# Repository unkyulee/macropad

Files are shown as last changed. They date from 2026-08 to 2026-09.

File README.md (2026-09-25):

# Macro Pad 

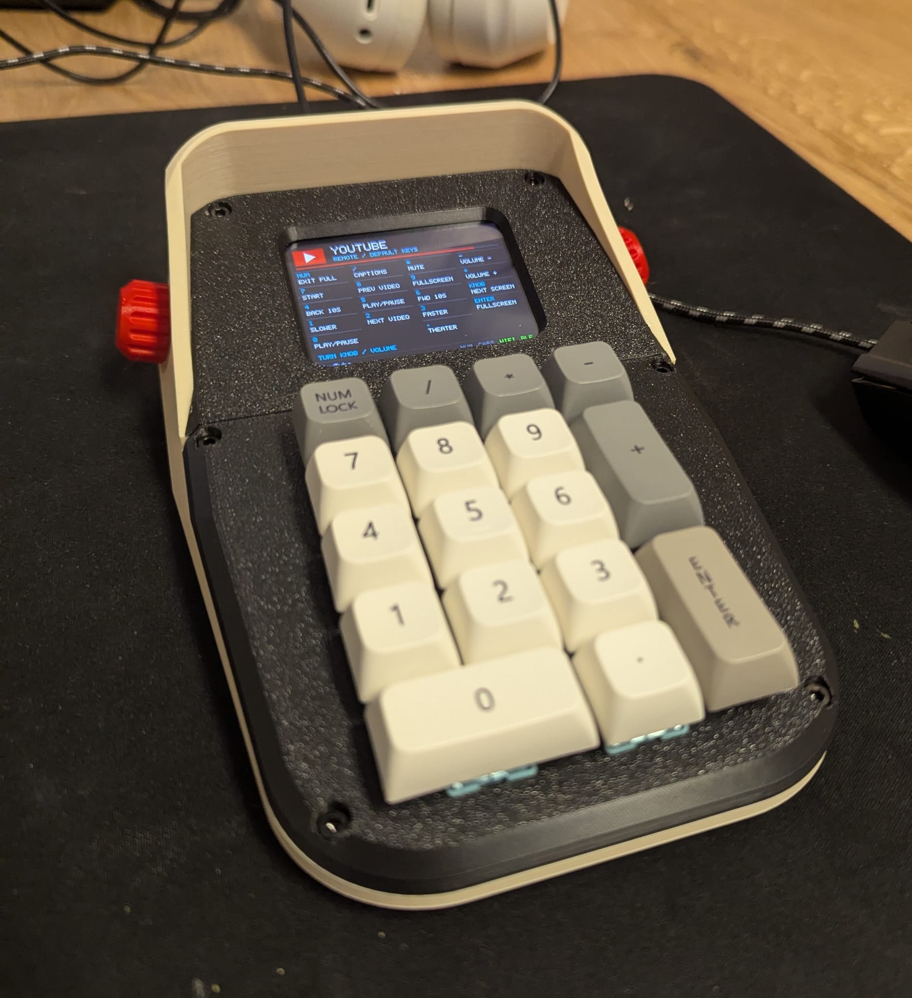
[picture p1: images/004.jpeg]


This is a number pad that also works as a macro pad. You can assign a different function to each key and save up to five different configurations.

I adjusted the overall dimensions and repositioned the knob to give it better proportions. I really like its size. It is quite chunky and has a strong presence on the desk. Since a number pad is usually idle most of the time, the screen displays a clock when it is not being used.

The screen can also play GIFs or turn the device into a standalone calculator. It connects to a PC or phone via Bluetooth Low Energy (BLE).

It solves several problems for me. I can type numbers much more comfortably, and most importantly, I can control movie playback from a distance, including playing and pausing, without having to reach for the keyboard.

It is a small device, but it has brought a noticeable improvement to my quality of life.

The STL files and firmware are available in this repository

Un Kyu Lee

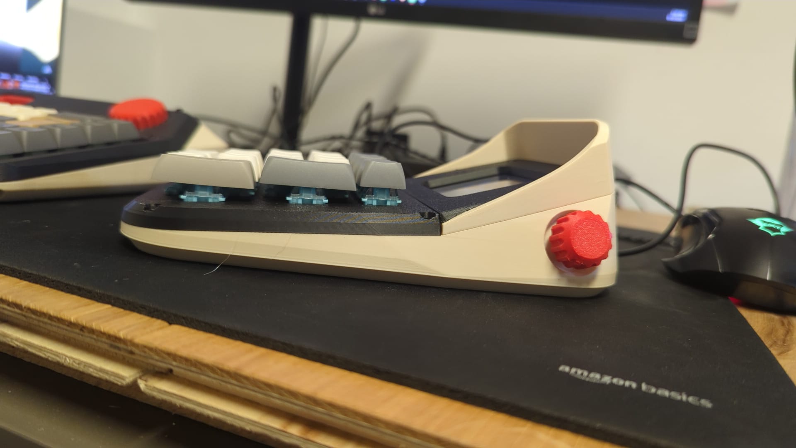
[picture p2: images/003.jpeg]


## Default screens

Press the knob to cycle through **Numpad → YouTube → Calculator → device info**.
Slots 4 and 5 are disabled until you enable them in the web interface. Turning the knob adjusts
the host volume on every screen.

1. **Numpad:** standard numeric keypad bindings, with the clock on the display.
2. **YouTube:** remote bindings and an animated red play button, with a
   keypad guide baked into the GIF showing the default actions. These labels
   are part of the image and do not change when you edit key bindings. Upload
   `src/data/gif/youtube.gif` through the web interface and select it for this
   screen. The default file path is `/gif/youtube.gif`; the firmware contains
   no embedded YouTube image. If the screen previously used the built-in GIF,
   select the uploaded file in its settings and save.
3. **Calculator:** standalone arithmetic using the printed digits and operators.
   Enter evaluates, Num Lock clears, and the decimal key enters a decimal point.

YouTube bindings (labels refer to the physical keycaps):

| Key | Action |
| --- | --- |
| `0` | Play/pause using Space |
| `4` / `6` | Rewind / forward 10 seconds |
| `8` / `2` | Previous / next video |
| `5` | Play/pause using K |
| `7` | Seek to the beginning |
| `9` or Enter | Toggle fullscreen |
| `1` / `3` | Slower / faster playback |
| `/` | Toggle captions |
| `*` | Toggle mute |
| `-` / `+` | Lower / raise player volume |
| `.` | Toggle theater mode |
| Num Lock | Exit fullscreen |

Click the YouTube player first so it receives the shortcuts. Previous video
(`Shift+P`) works within a playlist; next video (`Shift+N`) also works with
suggested videos. These bindings target the desktop web player; see
[YouTube's keyboard shortcuts](https://support.google.com/youtube/answer/7631406?hl=en).

Existing `/config.json` settings are preserved when updating the firmware. To
apply these factory defaults to an already configured device, use **Reset to
defaults** in the web interface after updating. This also resets saved Wi-Fi
networks and other custom settings, so save anything you want to keep first.
Alternatively, edit the three screen slots manually to preserve other settings.

The bundled GIF source is `src/scripts/generate_youtube_gif.py`; running it with
Python regenerates `src/data/gif/youtube.gif` for upload.

# Bill of Material

* [ILI9341 2.8" TFT LCD (240x320)](https://ko.aliexpress.com/item/1005006323532762.html)
  – Includes a built-in SD card slot (used in this build). Variations exist, so double-check dimensions if using the provided STL files.
  - If you can find the same dimension with ST7789 chip, it will still work and actually has a better quality. Just that it is a bit difficult to find than ILI9341

* [ESP32-S3 N16R8](https://www.amazon.com/Development-AYWHP-ESP32-S3-DevKitC-WROOM-1-N16R8-Compatible/dp/B0DG8L7MQ9)

* [Keypad PCB](./PCB)
  - You will need a PCB for the keypad. It is possible to handwire instead of using the PCB. Refer to the schematic to figure out the wiring in case of hand wiring

# Wiring Diagram

## ESP32-S3 and DISPLAY

The panel is two separate chips on one board: the **ILI9341** display controller and the
**XPT2046** resistive touch digitiser. They share a single SPI bus (SPI3 / HSPI) and are
told apart by their own chip selects — `TFT_CS` for the panel, `TOUCH_CS` for touch.
Eleven wires total, one of which is optional.

```
   ESP32-S3                              ILI9341 module
   ========                              ==============

   3V3      ───────────────────────────  VCC
   GND      ───────────────────────────  GND

   GPIO 12  ──┬────────────────────────  SCK     ┐
              └────────────────────────  T_CLK   │
   GPIO 11  ──┬────────────────────────  SDI     │  shared
              └────────────────────────  T_DIN   │  SPI bus
   GPIO 13  ──┬────────────────────────  SDO     │
              └────────────────────────  T_DO    ┘

   GPIO 10  ───────────────────────────  CS      ─  display select
   GPIO  3  ───────────────────────────  RESET
   GPIO 46  ───────────────────────────  DC / RS
   GPIO 14  ───────────────────────────  LED     ─  backlight

   GPIO  9  ───────────────────────────  T_CS    ─  touch select
```

## Display and touch

| ESP32-S3 | Module pin | Signal | Notes |
| --- | --- | --- | ----- |
| `3V3` | `VCC` | 3.3 V supply | Panel and both controllers are 3.3 V logic |
| `GND` | `GND` | Ground | Keep the return short, next to the SPI lines |
| `GPIO 12`| `SCK` `T_CLK` | SPI clock — shared | One clock, both chips |
| `GPIO 11`| `SDI` `T_DIN` | MOSI — shared | `SDI` on the panel, `T_DIN` on the digitiser |
| `GPIO 13`| `SDO` `T_DO`  | MISO — shared | **Required.** Touch is read-back only; no MISO, no coordinates |
| `GPIO 10`| `CS` | Display select | `TFT_CS` |
| `GPIO  3`| `RESET` | Panel reset | Strapping pin (JTAG source); safe as an output |
| `GPIO 46`| `DC` / `RS` | Data / command | Strapping pin; floats during reset, output after boot |
| `GPIO 14`| `LED` | Backlight | Module carries the series resistor; PWM here for brightness |
| `GPIO  9`| `T_CS` | Touch select | `TOUCH_CS` |
| `GPIO  8`| `T_IRQ` | Pen interrupt | Optional — TFT_eSPI polls instead. Wire it only for wake-on-touch |

The module's **SD card header is left unconnected**. Firmware storage is the internal
`storage` littlefs partition, formatted with 64 KB blocks to match the
S25FL128S flash. Files go on it through the web UI.

## ESP32-S3 and KEYPAD

A scanned 5 × 4 matrix. Nine GPIO carry 18 keys — 17 Cherry MX switches (`U1`–`U17`) plus
the knob's push button — each with a 1N4148 (`D1`–`D18`) so held keys can't ghost. Rows are
driven, columns are read; the knob's A/B ride the same ribbon.

```
   ESP32-S3                            CN2          Keypad PCB
   ========                         (12-pin)        ==========

   GPIO  1  ──────────────────────────  1  ───────── ROW 1   ┐
   GPIO  2  ──────────────────────────  2  ───────── ROW 2   │
   GPIO 42  ──────────────────────────  3  ───────── ROW 3   │  driven
   GPIO 41  ──────────────────────────  4  ───────── ROW 4   │
   GPIO 40  ──────────────────────────  5  ───────── ROW 5   ┘

   GPIO 39  ──────────────────────────  6  ───────── COL 1   ┐
   GPIO 45  ──────────────────────────  7  ───────── COL 2   │  read
   GPIO 48  ──────────────────────────  8  ───────── COL 3   │  (pull-up)
   GPIO 47  ──────────────────────────  9  ───────── COL 4   ┘

   GPIO  15  ───────────────────────── 10  ───────── KNOB A
   GPIO  16  ───────────────────────── 11  ───────── KNOB B
   GND      ────────────────────────── 12  ───────── GND

   one node:   ROW n ──┬── switch ──▶|── COL m
                       │     Uxx      Dxx
```

[PCB Schematic](./PCB/Schematic.pdf)

### Physical layout

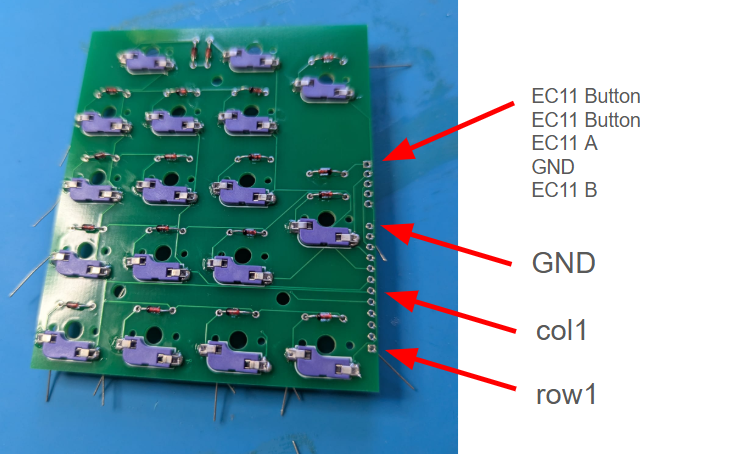
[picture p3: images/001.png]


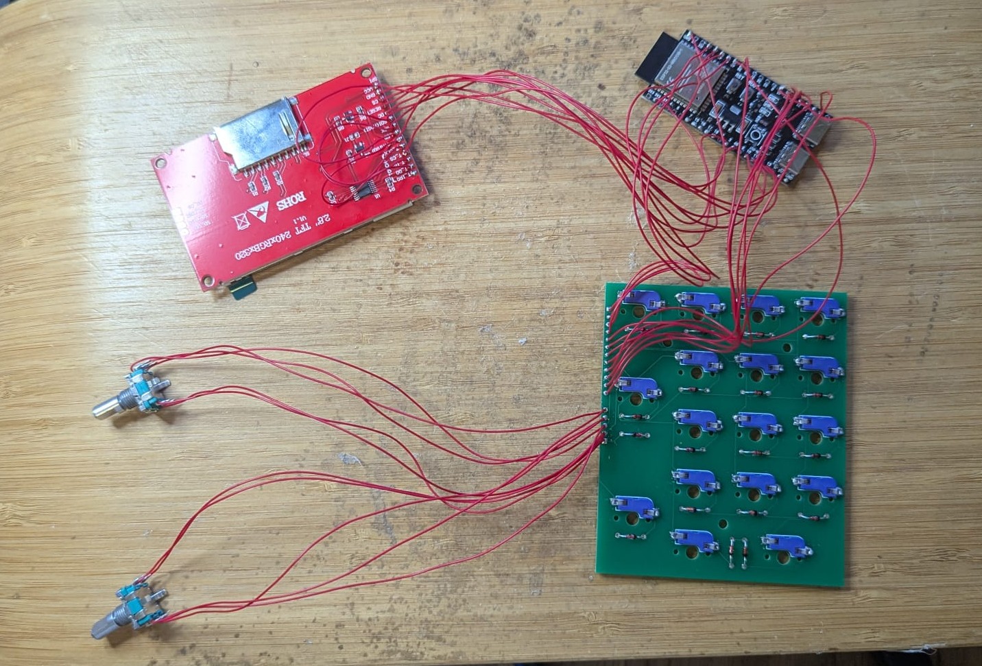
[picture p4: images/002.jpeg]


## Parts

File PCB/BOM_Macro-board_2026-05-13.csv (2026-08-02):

ID | Name | Designator | Footprint | Quantity | Manufacturer Part | Manufacturer | Supplier | Supplier Part | Price
1 | 22035125 | CN2 | CONN-TH_12P-P2.54_MOLEX_22035125 | 1 | 22035125 | MOLEX | LCSC | C586977 | 0.361
2 | HB-PH3-25415PB2GOP | KNOBRIGHT1 | HDR-TH_5P-P2.54-V-M | 1 | HB-PH3-25415PB2GOP | HANBO(汉博) | LCSC | C6332198 | 0.028
3 | 1N4148_C402212 | D1,D2,D3,D4,D5,D6,D7,D8,D9,D10,D11,D12,D13,D14,D15,D16,D17,D18 | DO-35_BD2.0-L4.2-P8.20-D0.5-RD | 18 | 1N4148 | LGE(鲁光) | LCSC | C402212 | 0.009
4 | CHERRY_MX_SWITCH | U1,U2,U3,U4,U5,U6,U7,U8,U9,U10,U11,U12,U13,U14,U15,U16,U17 | CHERRY-HOTSWAP-MOD | 17 |  |  | LCSC | CPG151101S11-16

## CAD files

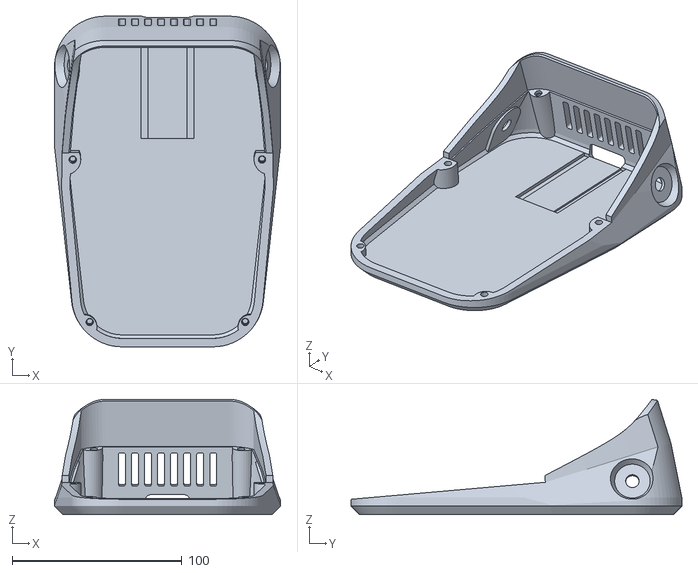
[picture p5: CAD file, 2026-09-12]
STL/Enclosure Bottom.stl
133.2 x 194.9 x 67.9

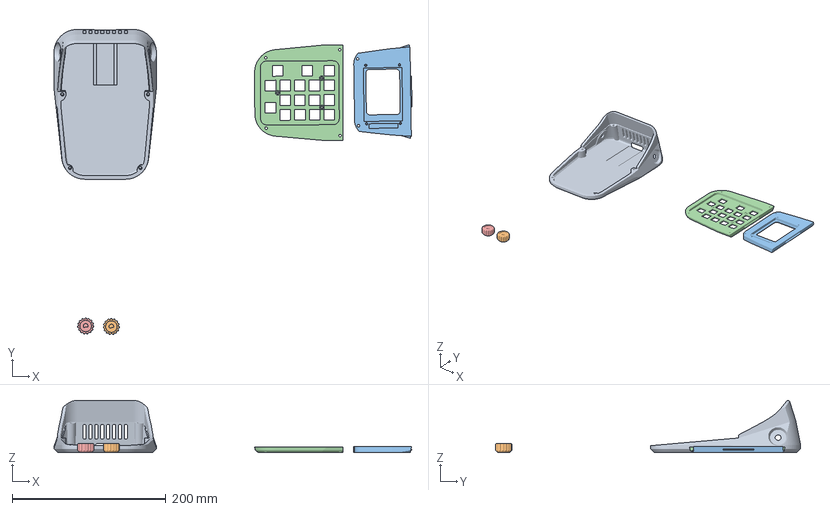
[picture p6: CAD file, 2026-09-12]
STL/macropad.3mf
465.6 x 396.9 x 67.9 mm
Enclosure Bottom.stl
Knob.stl x 2
Display Panel.stl
Keypad.stl

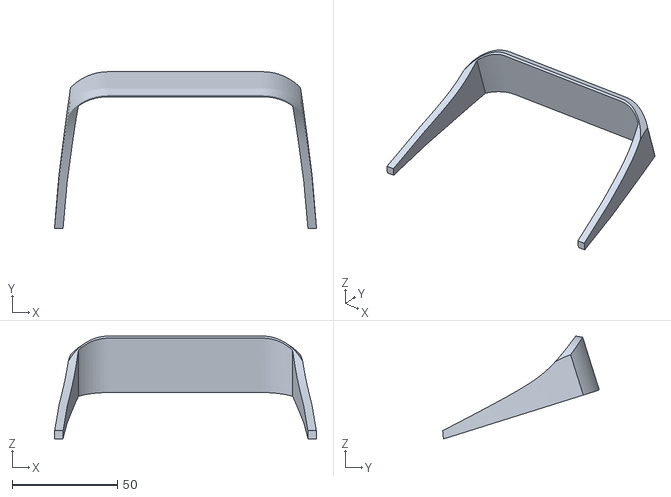
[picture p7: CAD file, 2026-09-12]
STL/Hood.stl
124.4 x 74.3 x 48.9

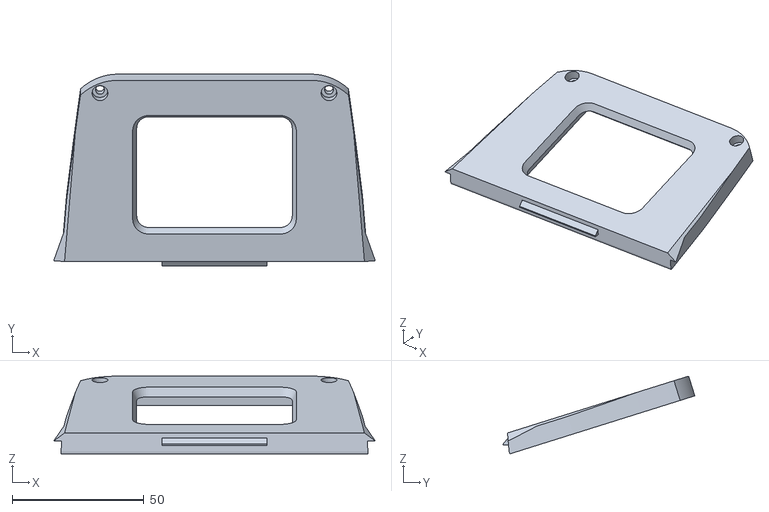
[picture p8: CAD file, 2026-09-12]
STL/Display Panel.stl
121.8 x 72.7 x 29.5

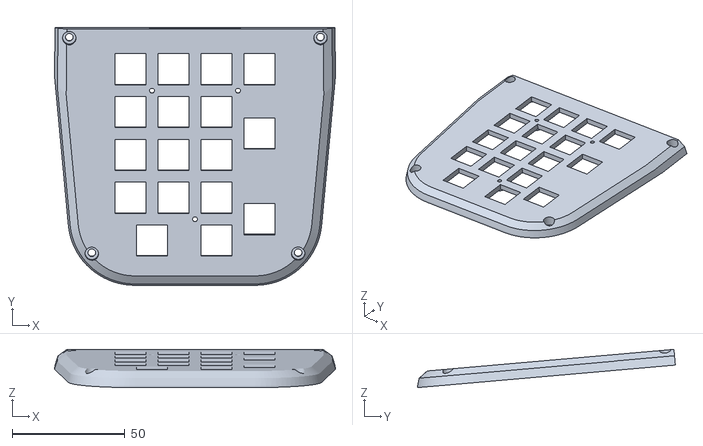
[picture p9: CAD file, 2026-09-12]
STL/Keypad.stl
124.8 x 114.5 x 17.0

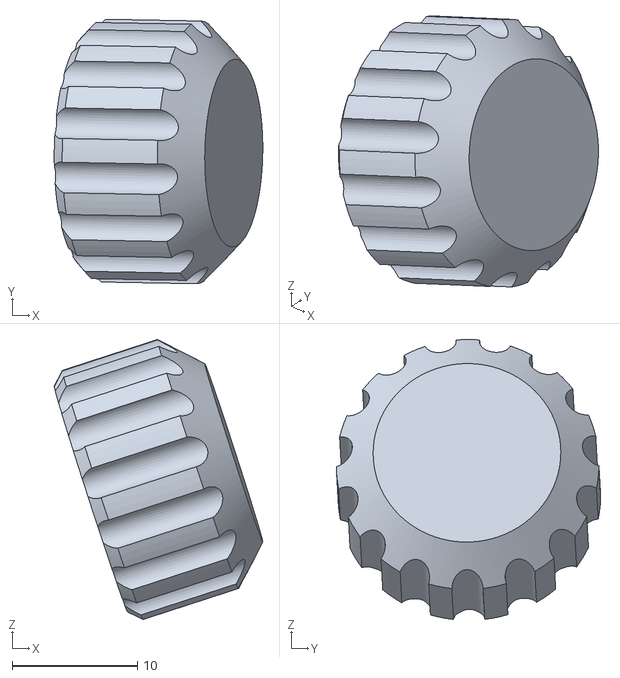
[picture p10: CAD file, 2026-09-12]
STL/Knob.stl
16.7 x 21.1 x 22.4

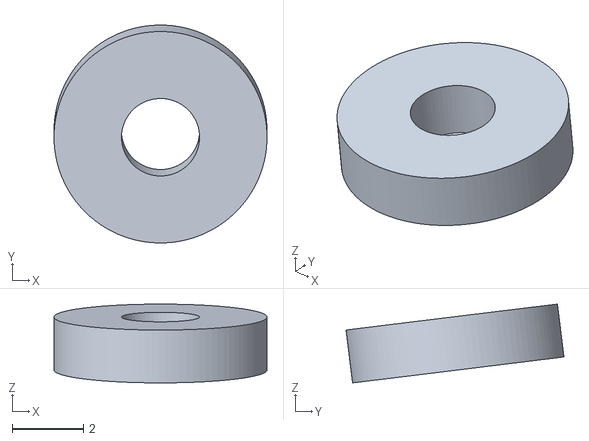
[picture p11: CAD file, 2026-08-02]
STL/PCB Holder.stl
6.00 x 6.14 x 2.22

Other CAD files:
STL/Macro Pad.f3d

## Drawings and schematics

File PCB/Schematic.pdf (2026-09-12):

## GND

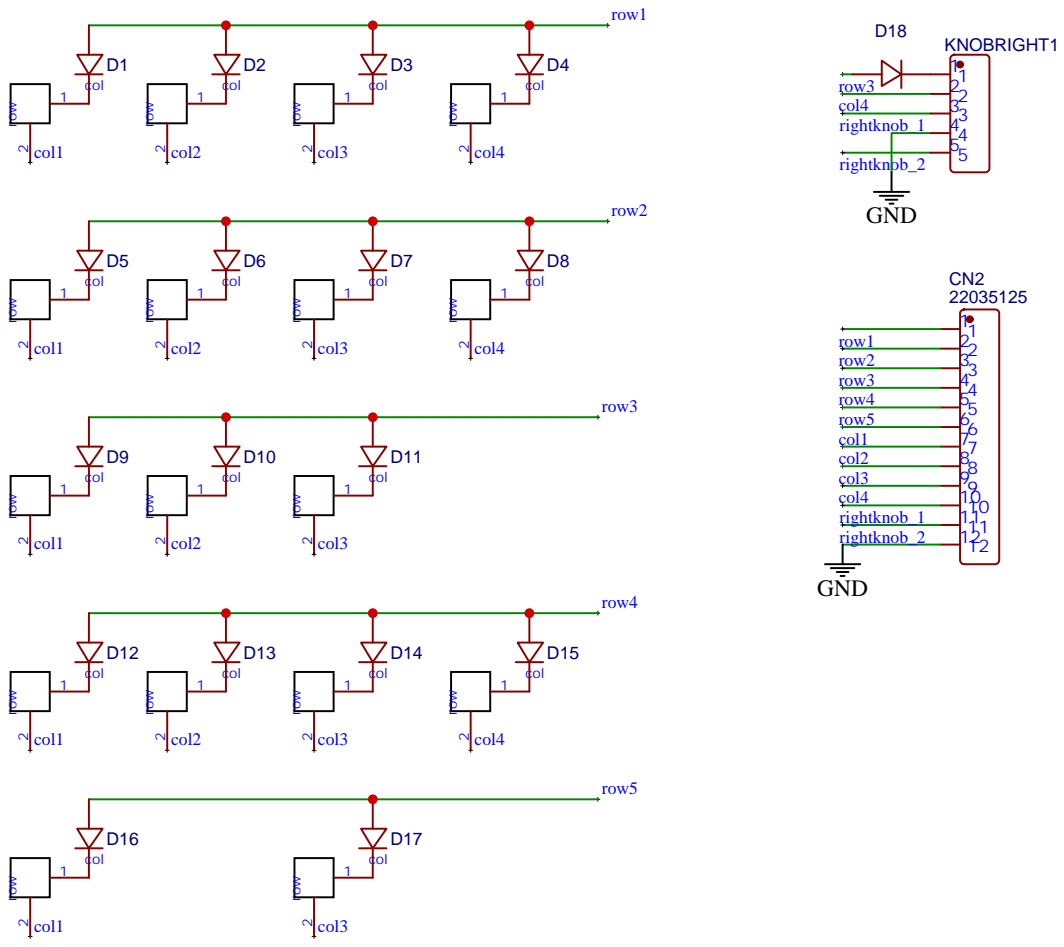
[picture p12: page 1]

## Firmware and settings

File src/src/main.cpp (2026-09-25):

#include <Arduino.h>

#include "app/app.h"
#include "display/display.h"
#include "keyboard/keyboard.h"
#include "service/Wifi/Wifi.h"
#include "service/WebUI/WebUI.h"

// WiFi association and HTTP request handling both block for long enough to
// be felt as key latency, so they get their own core. The Arduino loop
// already runs on core 1, so this task takes core 0.
static void NetworkCore(void *pvParameters)
{
    wifi_setup();
    webui_setup();

    while (true)
    {
        wifi_loop();
        webui_loop();
        delay(2);
    }
}

void setup()
{
    app_setup();

    display_setup();
    keyboard_setup();

    xTaskCreatePinnedToCore(
        NetworkCore,   // Function to run
        "NetworkCore", // Name
        8192,          // Stack size
        NULL,          // Parameters
        1,             // Priority
        NULL,          // Task handle
        0              // Core 0
    );
}

void loop()
{
    // read the keypad and the knob, then paint whatever changed
    keyboard_loop();
    display_loop();

    // Let the idle task run and avoid polling the display at full CPU speed.
    delay(1);
}

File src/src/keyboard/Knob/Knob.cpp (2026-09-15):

#include "Knob.h"
#include "app/app.h"
#include "keyboard/BLE/BLEKeypad.h"

#include <RotaryEncoder.h>

#define KNOB_PIN_A 16
#define KNOB_PIN_B 15

// FOUR3 is the latch mode for a detented EC11: one step per detent
static RotaryEncoder encoder(KNOB_PIN_A, KNOB_PIN_B, RotaryEncoder::LatchMode::FOUR3);

static void IRAM_ATTR knob_isr()
{
    encoder.tick();
}

//
void knob_setup()
{
    pinMode(KNOB_PIN_A, INPUT_PULLUP);
    pinMode(KNOB_PIN_B, INPUT_PULLUP);

    attachInterrupt(digitalPinToInterrupt(KNOB_PIN_A), knob_isr, CHANGE);
    attachInterrupt(digitalPinToInterrupt(KNOB_PIN_B), knob_isr, CHANGE);

    _log("Knob initialized (A=%d B=%d)\n", KNOB_PIN_A, KNOB_PIN_B);
}

//
void knob_loop()
{
    // the ISR keeps the state machine current, this only picks up the result
    static long lastPos = 0;

    long pos = encoder.getPosition();
    if (pos == lastPos)
        return;

    AppStatus &app = status();
    app.knobDelta = (pos > lastPos) ? 1 : -1;
    app.knob = pos;
    app.dirty = true;
    lastPos = pos;

    _log("[knob] position %ld direction %d\n", app.knob, app.knobDelta);

    ble_knob(app.knobDelta);
}

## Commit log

2026-08-02 draft macro keypad source code
    [BOM_Macro-board_2026-05-13.csv, Display Panel.stl, Enclosure Bottom.stl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]
2026-08-02 draft of web interface and BLE keyboard structure
    [partitions_16mb.csv]
2026-08-03 wifi setup working
    [partitions_16mb.csv]
2026-08-10 update design
    [Display Panel.stl, Enclosure Bottom.stl, Keypad.stl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]
2026-09-12 update the design
    [Display Panel.stl, Enclosure Bottom.stl, Hood.stl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]
2026-09-12 update crash
    [Hood.stl]
2026-09-12 design update
    [Enclosure Bottom.stl, Macro Pad.f3d, macropad.3mf]
2026-09-15 pin number mapping error fixed
    [Knob.cpp]
2026-09-25 led wiring on the display
2026-09-25 building it compatible with 64kb block flash chip. S25FL128S
    [partitions_16mb.csv]
